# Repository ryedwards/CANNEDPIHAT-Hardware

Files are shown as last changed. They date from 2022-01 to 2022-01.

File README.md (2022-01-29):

# CANNEDPIHAT-Hardware
 
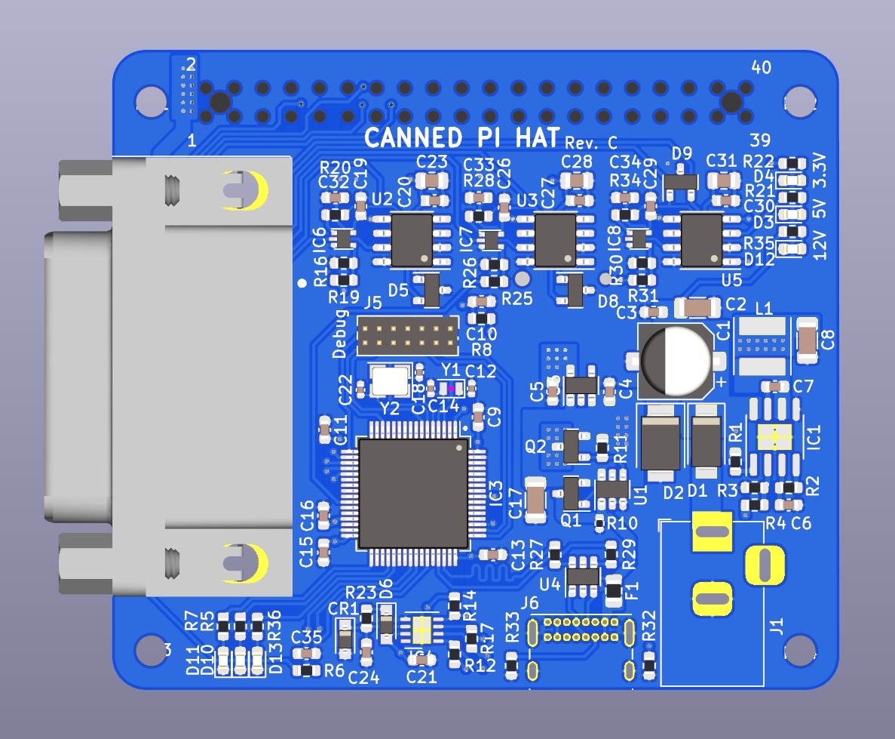
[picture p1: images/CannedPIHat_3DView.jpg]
CannedPiHat Front

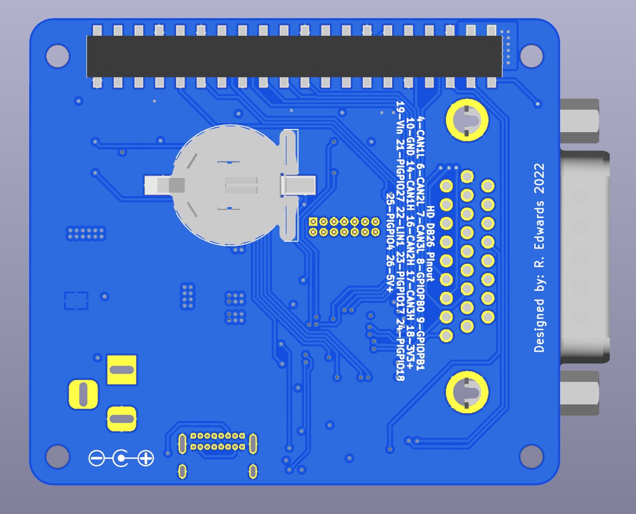
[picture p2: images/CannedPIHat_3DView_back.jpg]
CannedPiHat Front


## The CannedPi Hardware
Meet the CannedPi hardware!  This simple (and not prefectly designed) Raspberry PI Hat contains an STM32G4 microcontroller which can interface with the USB port of your Pi.

Why would I create such a Rube Goldberg design??
- I wanted a HAT that would provide provide solid 5V power from a ~12V power input.  This board has a 4A SMPS that provides more than enough juice for even a power hungry Pi4.
- I wanted the option of running both scripts on the Pi (Python-CAN, C applications, etc) while also having the ability to run real-time CAN on the embedded chip as needed.
- Wanted an "all-in-one" form factor for mounting on LCD displays and other small cases
- For LIN you really need the real time microcontroller
- I wanted to prove I could do it.  Now that I feel I've achived my goal I decided to share it wth everyone

## Features
- The 26-pin header provides access to all 3 CAN channels, the LIN channel, 12V, 5V, 3.3V and a few GPIO from both the PI and the SMT32G4.  Why a 26-pin?  Other CAN tools I'm using also utilize this header and I didn't feel like making new harnesses.  Besides, it's a nice form factor for getting a lot of I/O and there are cables available on Amazon.

## Notes
This design is provided in KiCad 6.0

## Disclaimers
It has not been EMI or EMC tested.  I am not a hardware engineer so I can't ensure that there aren't some design flaws.  I've sanity tested the prototypes and they seem to be stable and perform as expected.

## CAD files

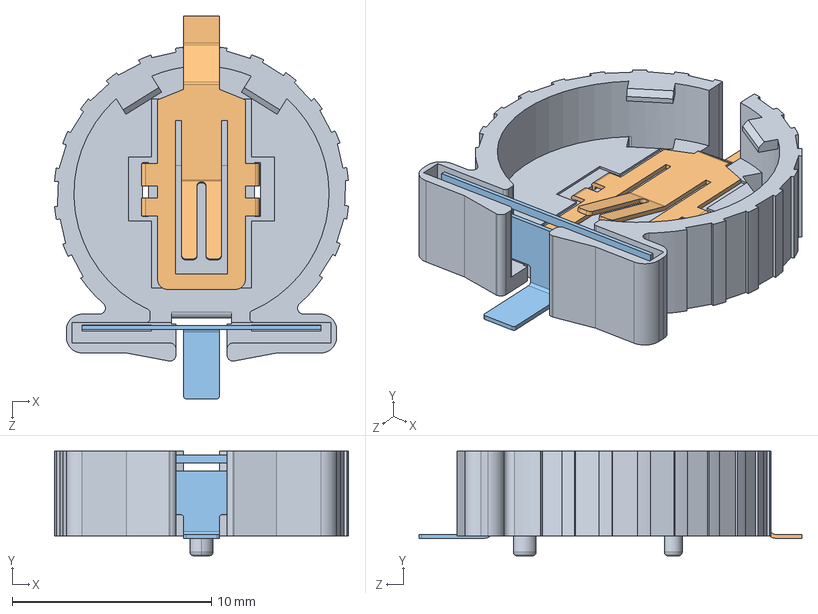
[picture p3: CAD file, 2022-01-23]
Custom_Parts/S8411-45R/3D/S8411-45R.stp
14.7 x 5.25 x 19.2 mm
Holder
Lower Contact
Rear Contact

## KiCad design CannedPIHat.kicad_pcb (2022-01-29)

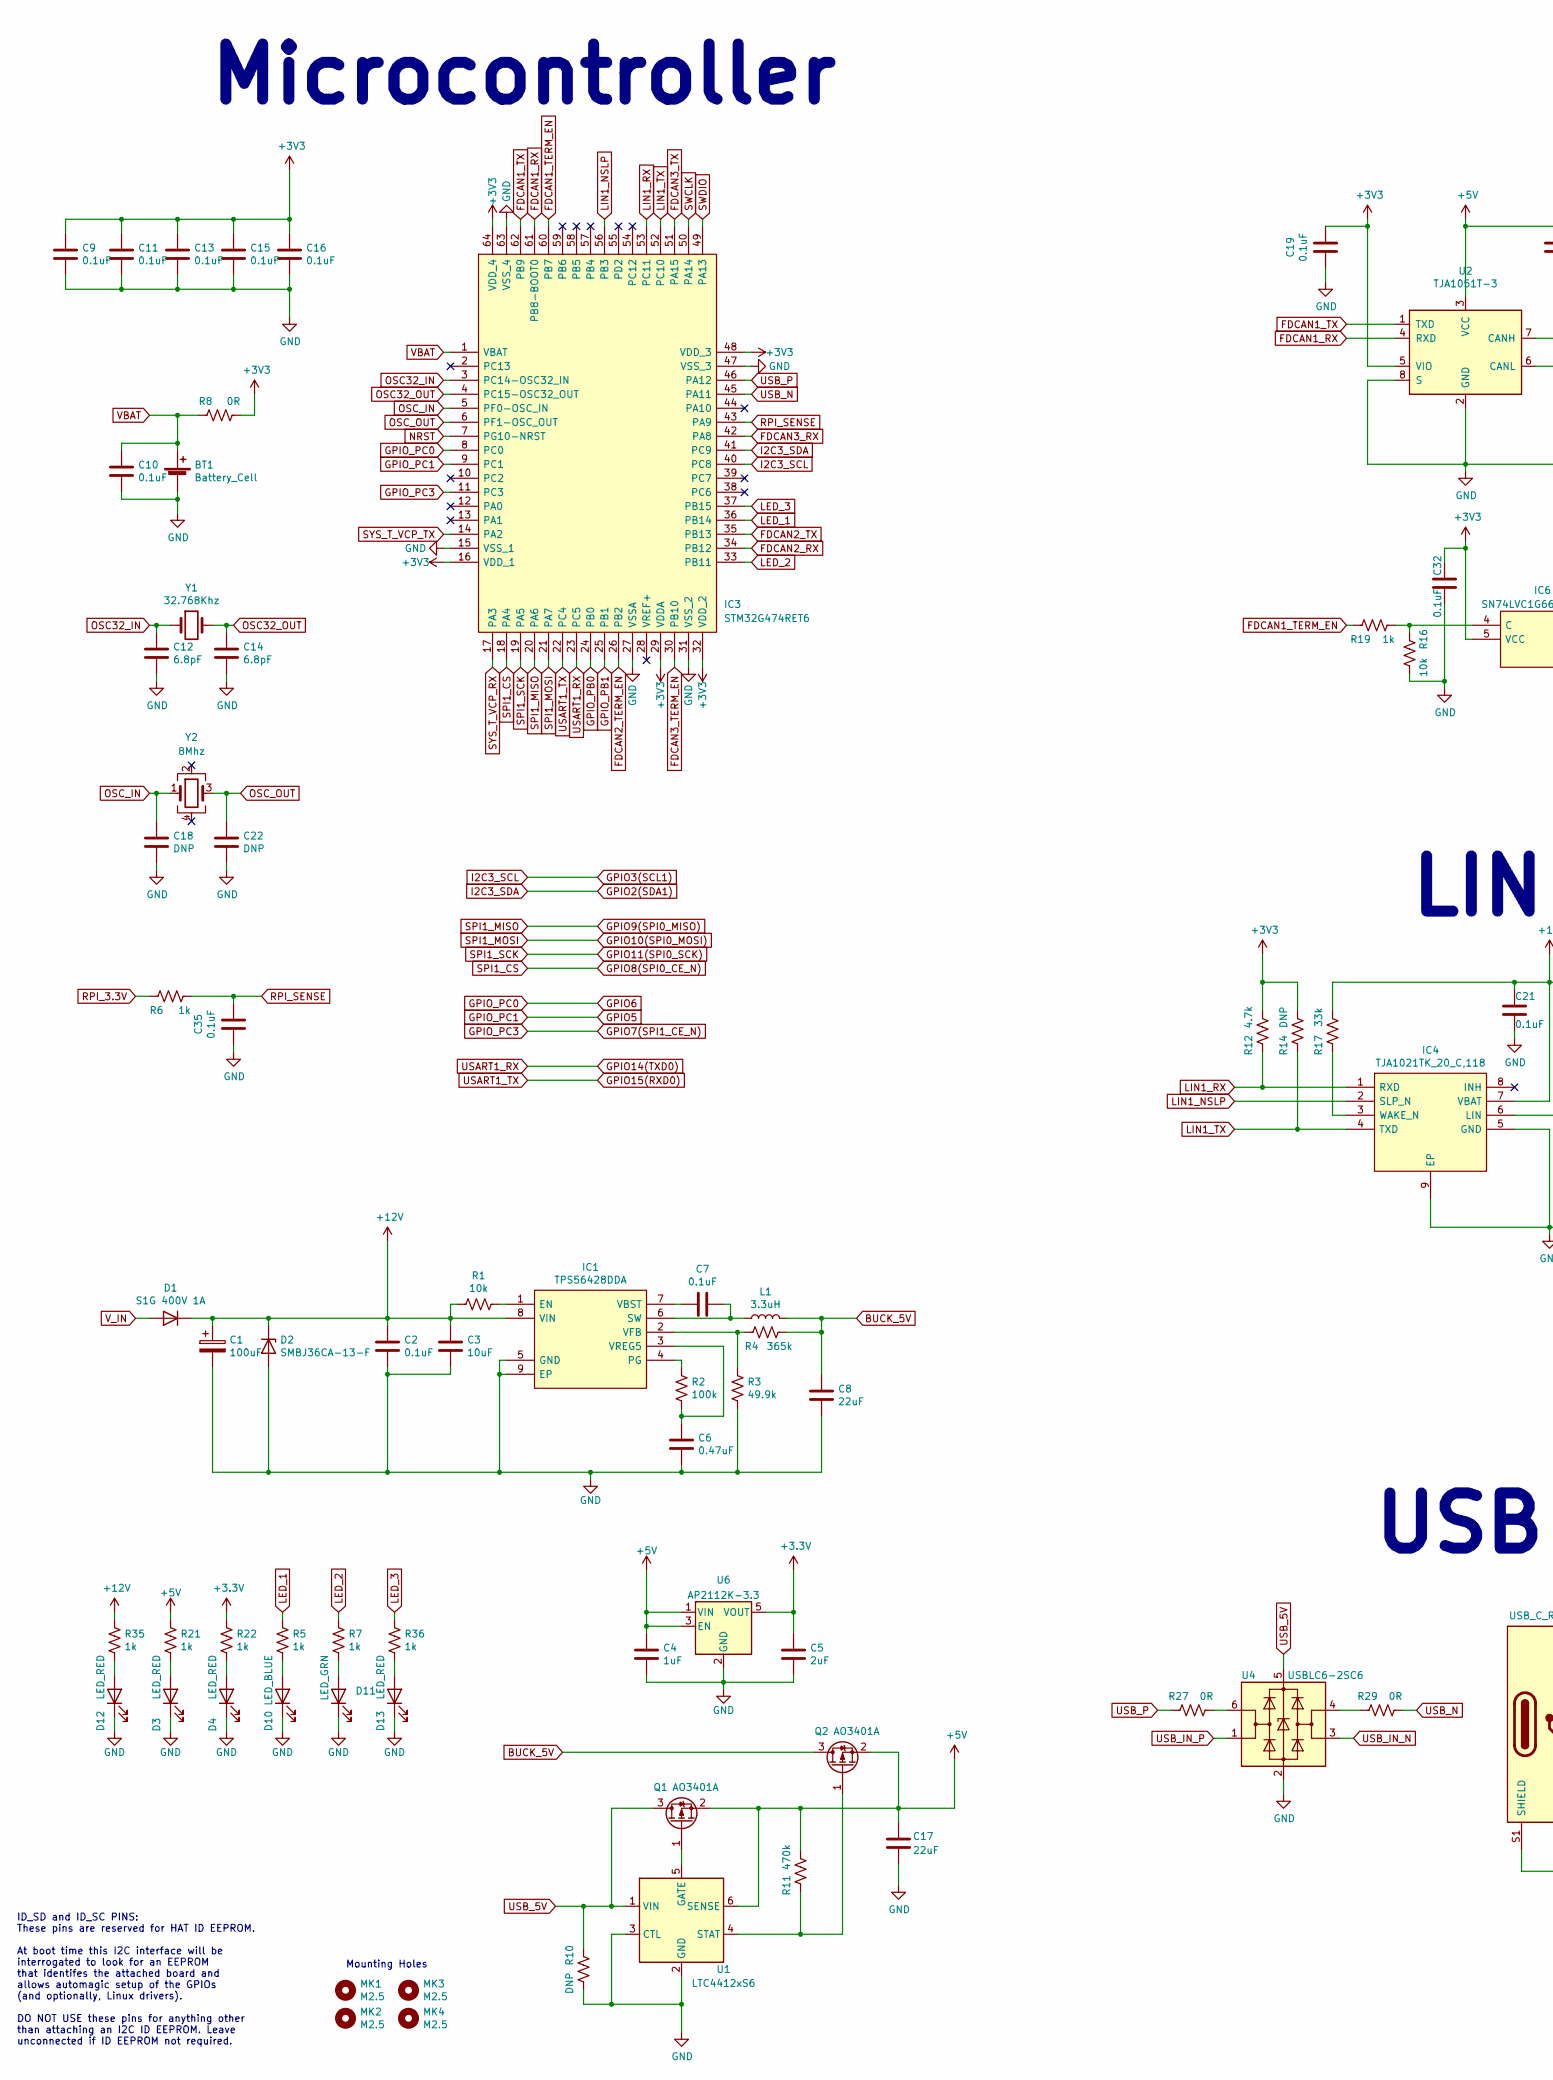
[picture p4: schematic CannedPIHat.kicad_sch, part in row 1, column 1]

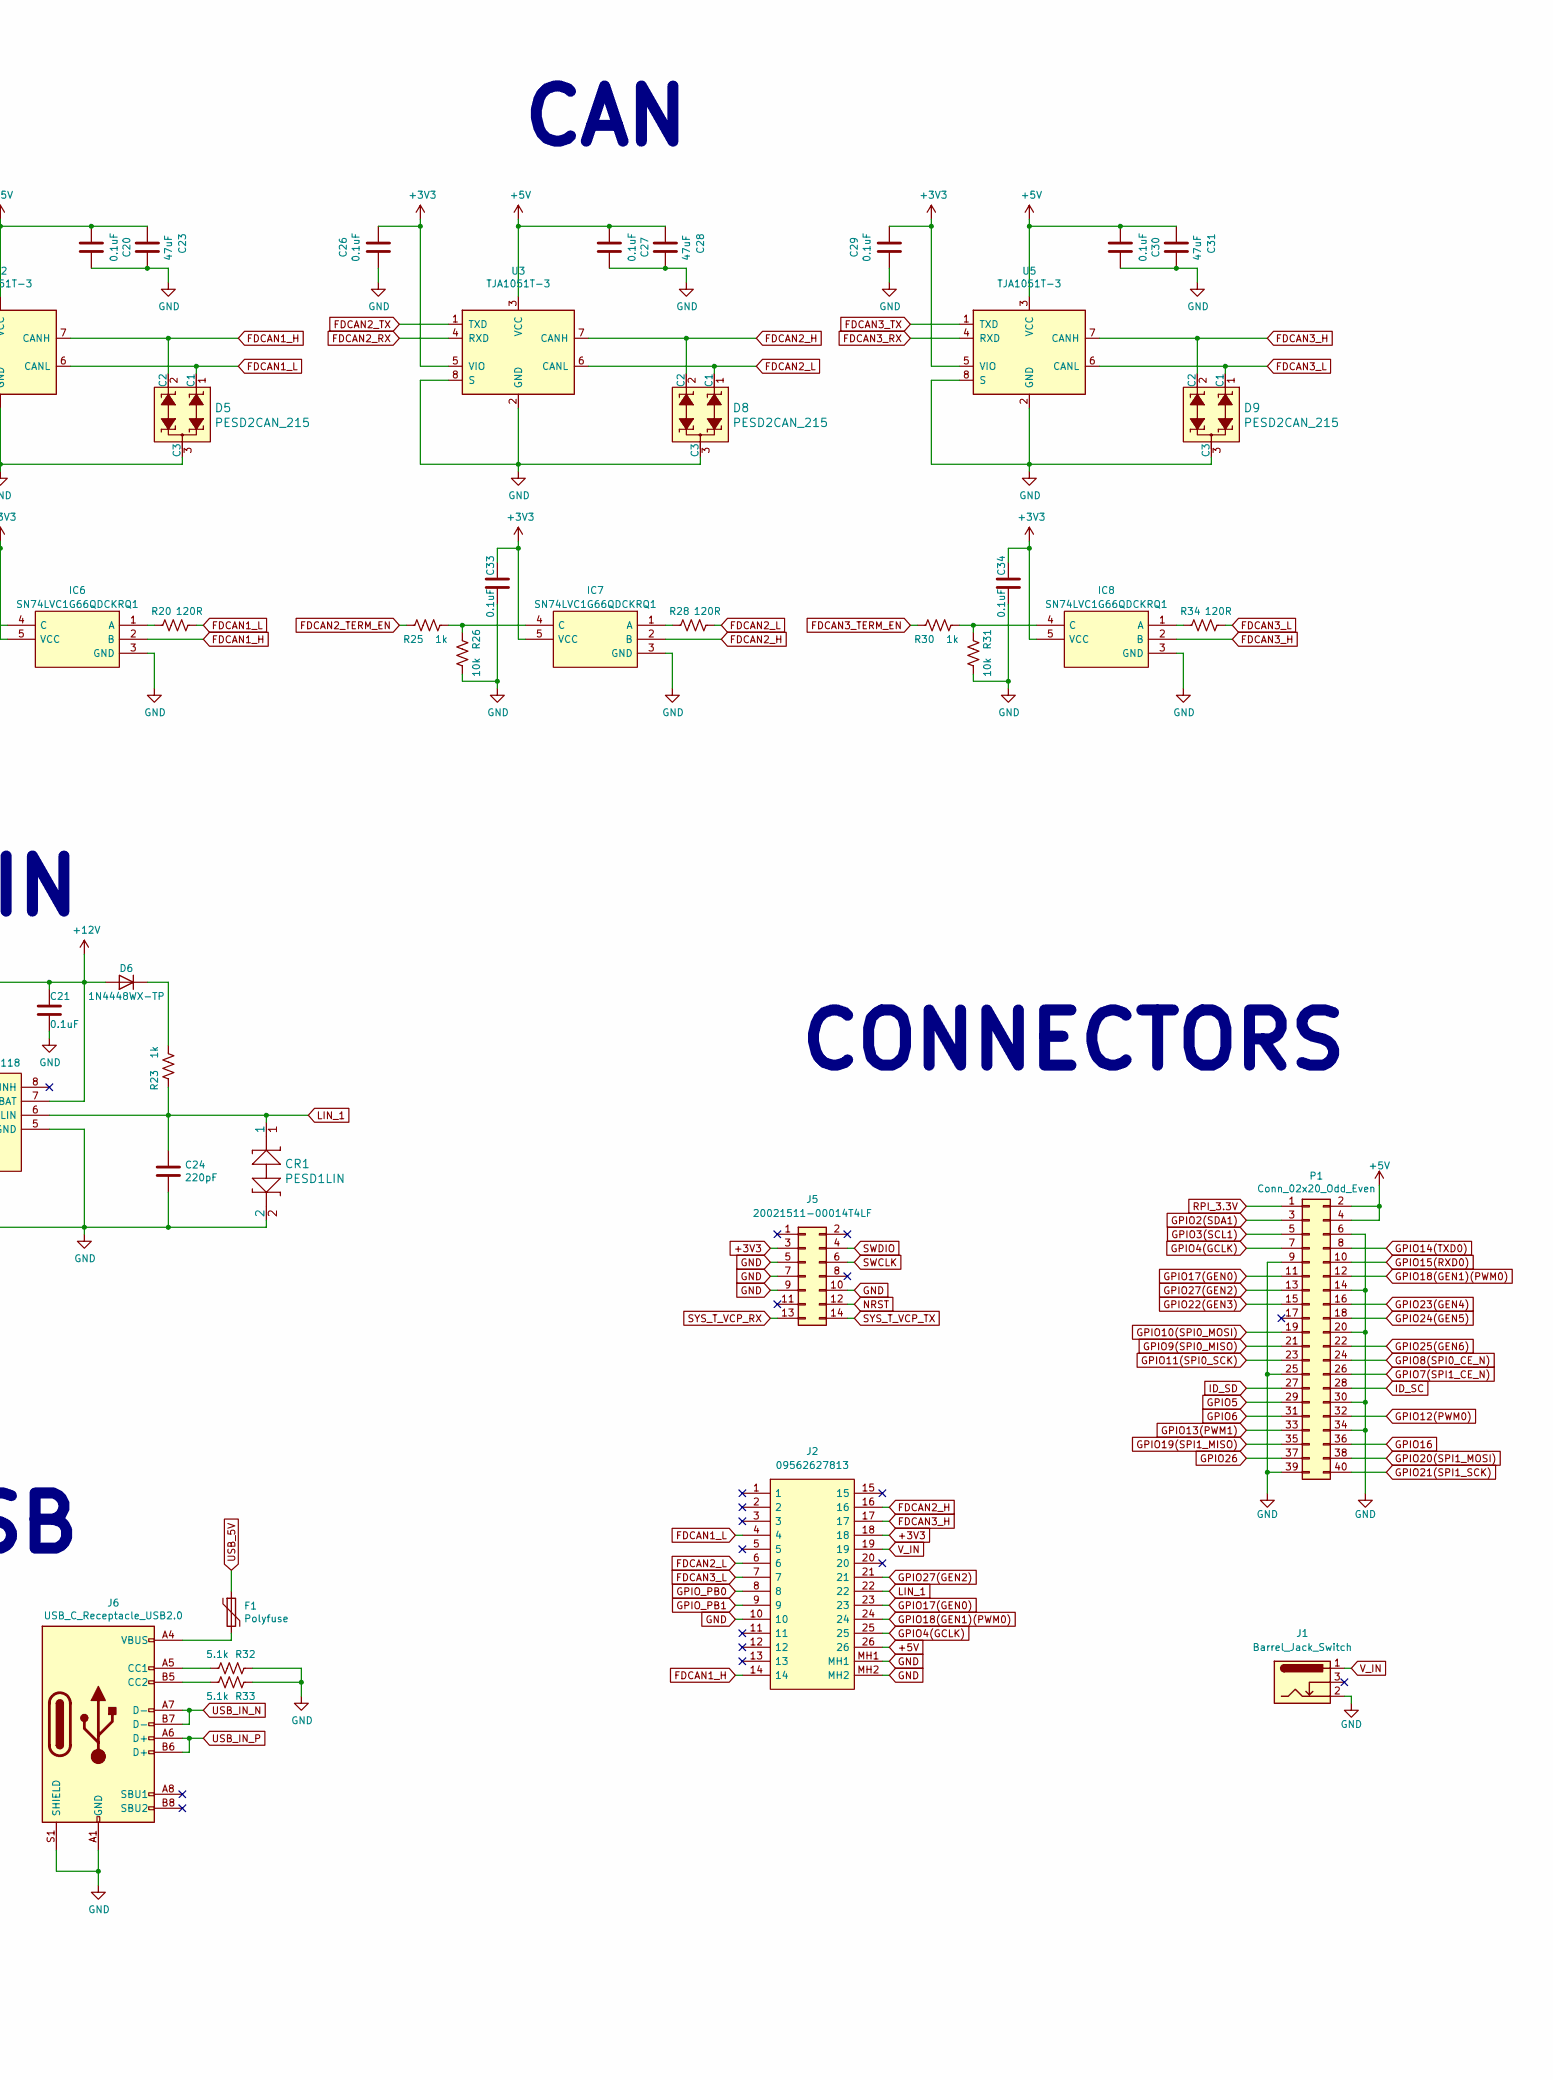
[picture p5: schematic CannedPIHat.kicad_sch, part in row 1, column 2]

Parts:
BT1: Battery_Cell; S8411-45R_1; Manufacturer_Part_Number S8411-45R; Digi-Key_PN 952-1745-1-ND
C1: 100uF; CP_Elec_6.3x7.7; Manufacturer_Part_Number EMZA250ADA101MF80G; LCSC Part # C127971
C2, C7, C9, C10, C11, C13, C15, C16, C19, C20, C21, C26, C27, C29, C30, C32, C33, C34, C35: 0.1uF; C_0603_1608Metric; Manufacturer_Part_Number CC0603KRX7R8BB104; LCSC Part # C14663
C3: 10uF; C_1206_3216Metric; Manufacturer_Part_Number CL31B106KQHNFNE; LCSC Part # C13585
C4: 1uF; C_0603_1608Metric; Manufacturer_Part_Number CC0603KRX7R8BB104; LCSC Part # C14663
C5: 2uF; C_0603_1608Metric; Manufacturer_Part_Number CC0603KRX7R8BB104; LCSC Part # C14663
C6: 0.47uF; C_0603_1608Metric; Manufacturer_Part_Number CGA3E2X7R2A472K080AA; LCSC Part # C2167812
C8, C17: 22uF; C_1206_3216Metric; Manufacturer_Part_Number EMK316ABJ226ML-T; LCSC Part # C12891
C12, C14: 6.8pF; C_0402_1005Metric; Manufacturer_Part_Number GRM1555C1H6R8CA01D; LCSC Part # C1576
C18, C22: DNP; C_0402_1005Metric; LCSC Part # C1576
C23, C28, C31: 47uF; C_0805_2012Metric; Manufacturer_Part_Number JMK212BBJ476MG-T; LCSC Part # C16780
C24: 220pF; C_0603_1608Metric; Manufacturer_Part_Number CC0603JRNPO9BN221; LCSC Part # C1603
CR1: PESD1LIN; D_SOD-323_HandSoldering; Manufacturer_Part_Number PESD1LIN,135; LCSC Part # C2831530
D1: S1G 400V 1A; D_SMA; Manufacturer_Part_Number S1G; LCSC Part # C412437
D2: SMBJ36CA-13-F; D_SMB; Manufacturer_Part_Number SMBJ36CA-13-F; LCSC Part # C78421
D3, D4, D12, D13: LED_RED; LED_0603_1608Metric; Manufacturer_Part_Number LS Q976-NR-1; LCSC Part # C2286
D5, D8, D9: PESD2CAN_215; SOT-23; MPN PESD2CAN,215; Digi-Key_PN 1727-3891-1-ND
D6: ‎1N4448WX-TP‎; D_SOD-323_HandSoldering; Manufacturer_Part_Number ‎1N4448WX-TP‎; Digi-Key_PN 1N4448WXTPMSCT-ND
D10: LED_BLUE; LED_0603_1608Metric; Manufacturer_Part_Number LB Q39E-N1OO-35-1; LCSC Part # C72041
D11: LED_GRN; LED_0603_1608Metric; Manufacturer_Part_Number LG Q396-PS-35; LCSC Part # C72043
F1: Polyfuse; Fuse_0805_2012Metric; Manufacturer_Part_Number 0ZCK0035FF2G; LCSC Part # C369150
IC1: TPS56428DDA; SOIC-8-1EP_3.9x4.9mm_P1.27mm_EP2.29x3mm_ThermalVias; Mouser Part Number 595-TPS56428DDA
IC3: STM32G474RET6; LQFP-64_10x10mm_P0.5mm; Mouser Part Number 511-STM32G474RET6
IC4: TJA1021TK_20_C,118; HVSON-8-1EP_3x3mm_P0.65mm_EP1.6x2.4mm; Mouser Part Number 771-TJA1021TK20C1
IC6, IC7, IC8: SN74LVC1G66QDCKRQ1; SOT-665; Mouser Part Number 595-LVC1G66QDCKRQ1
J1: Barrel_Jack_Switch; BarrelJack_Horizontal
J2: 09562627813; Manufacturer_Part_Number 09562627813; Mouser Part Number 617-09-56-262-7813
J5: 20021511-00014T4LF; PinHeader_2x07_P1.27mm_Vertical; Mouser Part Number 200-FTSH10701LDK
J6: USB_C_Receptacle_USB2.0; USB_C_Receptacle_GCT_USB4085; Manufacturer_Part_Number USB4085-GF-A; Digi-Key_PN 2073-USB4085-GF-ACT-ND
L1: 3.3uH; L_Taiyo-Yuden_NR-50xx; LCSC Part # C167908
MK1, MK2, MK3, MK4: M2.5; MountingHole_2.7mm_M2.5
P1: Conn_02x20_Odd_Even; M207812045_MIRROR; Manufacturer_Part_Number M20-7812045R; Digi-Key_PN 952-3230-2-ND
Q1, Q2: AO3401A; SOT-23; LCSC Part # C15127
R1, R16, R26, R31: 10k; R_0603_1608Metric; Manufacturer_Part_Number RC0603FR-0710KL; LCSC Part # C25804
R2: 100k; R_0603_1608Metric; Manufacturer_Part_Number RC0603FR-07100KL; LCSC Part # C25803
R3: 49.9k; R_0603_1608Metric; Manufacturer_Part_Number AF0603FR-0749K9L; LCSC Part # C23184
R4: 365k; R_0603_1608Metric; Manufacturer_Part_Number 13-AC0603FR-07365KLCT-ND; LCSC Part # C23031
R5, R6, R7, R19, R21, R22, R23, R25, R30, R35, R36: 1k; R_0603_1608Metric; Manufacturer_Part_Number RC0603FR-071KL; LCSC Part # C21190
R8, R27, R29: 0R; R_0603_1608Metric; Manufacturer_Part_Number RC0603JR-070RL; LCSC Part # C21189
R10: DNP; R_0402_1005Metric
R11: 470k; R_0603_1608Metric; LCSC Part # C23178
R12: 4.7k; R_0603_1608Metric; Manufacturer_Part_Number RC0603JR-074K7L; LCSC Part # C23162
R14: DNP; R_0603_1608Metric
R17: 33k; R_0603_1608Metric; Manufacturer_Part_Number RC0603FR-0733K2L; LCSC Part # C4216
R20, R28, R34: 120R; R_0603_1608Metric; Manufacturer_Part_Number RC0603FR-07120RL; LCSC Part # C22787
R32, R33: 5.1k; R_0603_1608Metric; Manufacturer_Part_Number RC0603JR-075K1L; LCSC Part # C23186
U1: LTC4412xS6; TSOT-23-6; LCSC Part # C514442
U2, U3, U5: TJA1051T-3; SOIC-8_3.9x4.9mm_P1.27mm; LCSC Part # C38695
U4: USBLC6-2SC6; SOT-23-6; Manufacturer_Part_Number USBLC6-2SC6; LCSC Part # C2687116
U6: AP2112K-3.3; SOT-23-5
Y1: 32.768Khz; Crystal_SMD_2012-2Pin_2.0x1.2mm; Manufacturer_Part_Number ECS-.327-6-12-C-TR; LCSC Part # C276423
Y2: 8Mhz; Crystal_SMD_3225-4Pin_3.2x2.5mm

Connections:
+5V: C4.1, C17.1, C20.2, C23.1, C27.2, C28.1, C30.2, C31.1, J2.26, P1.2, P1.4, Q1.2 (S), Q2.2 (S), R11.2, R21.2, U1.6 (SENSE), U2.3 (VCC), U3.3 (VCC), U5.3 (VCC), U6.1 (VIN), U6.3 (EN)
+12V: C1.1, C2.1, C3.1, C21.1, D1.1 (K), D2.1 (K), D6.2 (A), IC1.8 (VIN), IC4.7 (VBAT), R1.2, R17.2, R35.2
BUCK_5V: C8.1, L1.2, Q2.3 (D), R4.1
FDCAN1_H: D5.2 (C2), IC6.2 (B), J2.14, U2.7 (CANH)
FDCAN1_L: D5.1 (C1), J2.4, R20.2, U2.6 (CANL)
FDCAN1_RX: IC3.61 (PB8-BOOT0), U2.4 (RXD)
FDCAN1_TERM_EN: IC3.60 (PB7), R19.1
FDCAN1_TX: IC3.62 (PB9), U2.1 (TXD)
FDCAN2_H: D8.2 (C2), IC7.2 (B), J2.16, U3.7 (CANH)
FDCAN2_L: D8.1 (C1), J2.6, R28.2, U3.6 (CANL)
FDCAN2_RX: IC3.34 (PB12), U3.4 (RXD)
FDCAN2_TERM_EN: IC3.26 (PB2), R25.1
FDCAN2_TX: IC3.35 (PB13), U3.1 (TXD)
FDCAN3_H: D9.2 (C2), IC8.2 (B), J2.17, U5.7 (CANH)
FDCAN3_L: D9.1 (C1), J2.7, R34.2, U5.6 (CANL)
FDCAN3_RX: IC3.42 (PA8), U5.4 (RXD)
FDCAN3_TERM_EN: IC3.30 (PB10), R30.1
FDCAN3_TX: IC3.51 (PA15), U5.1 (TXD)
GND: BT1.2 (-), C1.2, C2.2, C3.2, C4.2, C5.2, C6.2, C8.2, C9.2, C10.2, C11.2, C12.2, C13.2, C14.2, C15.2, C16.2, C17.2, C18.2, C19.2, C20.1, C21.2, C22.2, C23.2, C24.2, C26.2, C27.1, C28.2, C29.2, C30.1, C31.2, C32.2, C33.2, C34.2, C35.2, CR1.2, D2.2 (A), D3.1 (K), D4.1 (K), D5.3 (C3), D8.3 (C3), D9.3 (C3), D10.1 (K), D11.1 (K), D12.1 (K), D13.1 (K), IC1.5 (GND), IC1.9 (EP), IC3.15 (VSS_1), IC3.27 (VSSA), IC3.31 (VSS_2), IC3.47 (VSS_3), IC3.63 (VSS_4), IC4.5 (GND), IC4.9 (EP), IC6.3 (GND), IC7.3 (GND), IC8.3 (GND), J1.2, J2.10, J2.MH1, J2.MH2, J5.5, J5.7, J5.9, J5.10, J6.A1 (GND), J6.A12 (GND), J6.B1 (GND), J6.B12 (GND), J6.S1 (SHIELD), P1.6, P1.9, P1.14, P1.20, P1.25, P1.30, P1.34, P1.39, R3.2, R10.2, R16.2, R26.2, R31.2, R32.1, R33.1, U1.2 (GND), U1.3 (CTL), U2.2 (GND), U2.8 (S), U3.2 (GND), U3.8 (S), U4.2 (GND), U5.2 (GND), U5.8 (S), U6.2 (GND)
GPIO2(SDA1): IC3.41 (PC9), P1.3
GPIO3(SCL1): IC3.40 (PC8), P1.5
GPIO4(GCLK): J2.25, P1.7
GPIO5: IC3.9 (PC1), P1.29
GPIO6: IC3.8 (PC0), P1.31
GPIO7(SPI1_CE_N): IC3.11 (PC3), P1.26
GPIO8(SPI0_CE_N): IC3.18 (PA4), P1.24
GPIO9(SPI0_MISO): IC3.20 (PA6), P1.21
GPIO10(SPI0_MOSI): IC3.21 (PA7), P1.19
GPIO11(SPI0_SCK): IC3.19 (PA5), P1.23
GPIO12(PWM0): P1.32
GPIO13(PWM1): P1.33
GPIO14(TXD0): IC3.23 (PC5), P1.8
GPIO15(RXD0): IC3.22 (PC4), P1.10
GPIO16: P1.36
GPIO17(GEN0): J2.23, P1.11
GPIO18(GEN1)(PWM0): J2.24, P1.12
GPIO19(SPI1_MISO): P1.35
GPIO20(SPI1_MOSI): P1.38
GPIO21(SPI1_SCK): P1.40
GPIO22(GEN3): P1.15
GPIO23(GEN4): P1.16
GPIO24(GEN5): P1.18
GPIO25(GEN6): P1.22
GPIO26: P1.37
GPIO27(GEN2): J2.21, P1.13
GPIO_PB0: IC3.24 (PB0), J2.8
GPIO_PB1: IC3.25 (PB1), J2.9
ID_SC: P1.28
ID_SD: P1.27
LED_1: IC3.36 (PB14), R5.2
LED_2: IC3.33 (PB11), R7.2
LED_3: IC3.37 (PB15), R36.2
LIN1_NSLP: IC3.56 (PB3), IC4.2 (SLP_N)
LIN1_RX: IC3.53 (PC11), IC4.1 (RXD), R12.1
LIN1_TX: IC3.52 (PC10), IC4.4 (TXD), R14.1
LIN_1: C24.1, CR1.1, IC4.6 (LIN), J2.22, R23.1
NRST: IC3.7 (PG10-NRST), J5.12
unnamed: C6.1, IC1.3 (VREG5), R2.2
unnamed: C7.1, IC1.6 (SW), L1.1
unnamed: C7.2, IC1.7 (VBST)
unnamed: D3.2 (A), R21.1
unnamed: D4.2 (A), R22.1
unnamed: D6.1 (K), R23.2
unnamed: D10.2 (A), R5.1
unnamed: D11.2 (A), R7.1
unnamed: D12.2 (A), R35.1
unnamed: D13.2 (A), R36.1
unnamed: F1.2, J6.A4 (VBUS), J6.A9 (VBUS), J6.B4 (VBUS), J6.B9 (VBUS)
unnamed: IC1.1 (EN), R1.1
unnamed: IC1.2 (VFB), R3.1, R4.2
unnamed: IC1.4 (PG), R2.1
unnamed: IC4.3 (WAKE_N), R17.1
unnamed: IC6.1 (A), R20.1
unnamed: IC6.4 (C), R16.1, R19.2
unnamed: IC7.1 (A), R28.1
unnamed: IC7.4 (C), R25.2, R26.1
unnamed: IC8.1 (A), R34.1
unnamed: IC8.4 (C), R30.2, R31.1
unnamed: J6.A5 (CC1), R32.2
unnamed: J6.B5 (CC2), R33.2
unnamed: Q1.1 (G), U1.5 (GATE)
unnamed: Q2.1 (G), R11.1, U1.4 (STAT)
unnamed: R27.2, U4.6 (I/O1)
unnamed: R29.1, U4.4 (I/O2)
OSC32_IN: C12.1, IC3.3 (PC14-OSC32_IN), Y1.1
OSC32_OUT: C14.1, IC3.4 (PC15-OSC32_OUT), Y1.2
OSC_IN: C18.1, IC3.5 (PF0-OSC_IN), Y2.1
OSC_OUT: C22.1, IC3.6 (PF1-OSC_OUT), Y2.3
RPI_3.3V: P1.1, R6.1
RPI_SENSE: C35.1, IC3.43 (PA9), R6.2
SWCLK: IC3.50 (PA14), J5.6
SWDIO: IC3.49 (PA13), J5.4
SYS_T_VCP_RX: IC3.17 (PA3), J5.13
SYS_T_VCP_TX: IC3.14 (PA2), J5.14
USB_5V: F1.1, Q1.3 (D), R10.1, U1.1 (VIN), U4.5 (VBUS)
USB_IN_N: J6.A7 (D-), J6.B7 (D-), U4.3 (I/O2)
USB_IN_P: J6.A6 (D+), J6.B6 (D+), U4.1 (I/O1)
USB_N: IC3.45 (PA11), R29.2
USB_P: IC3.46 (PA12), R27.1
VBAT: BT1.1 (+), C10.1, IC3.1 (VBAT), R8.1
V_IN: D1.2 (A), J1.1, J2.19

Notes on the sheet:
Mounting Holes
CAN
LIN
Microcontroller
USB
CONNECTORS
ID_SD and ID_SC PINS: These pins are reserved for HAT ID EEPROM. At boot time this I2C interface will be interrogated to look for an EEPROM that identifes the attached board and allows automagic setup of the GPIOs (and optionally, Linux drivers). DO NOT USE these pins for anything other than attach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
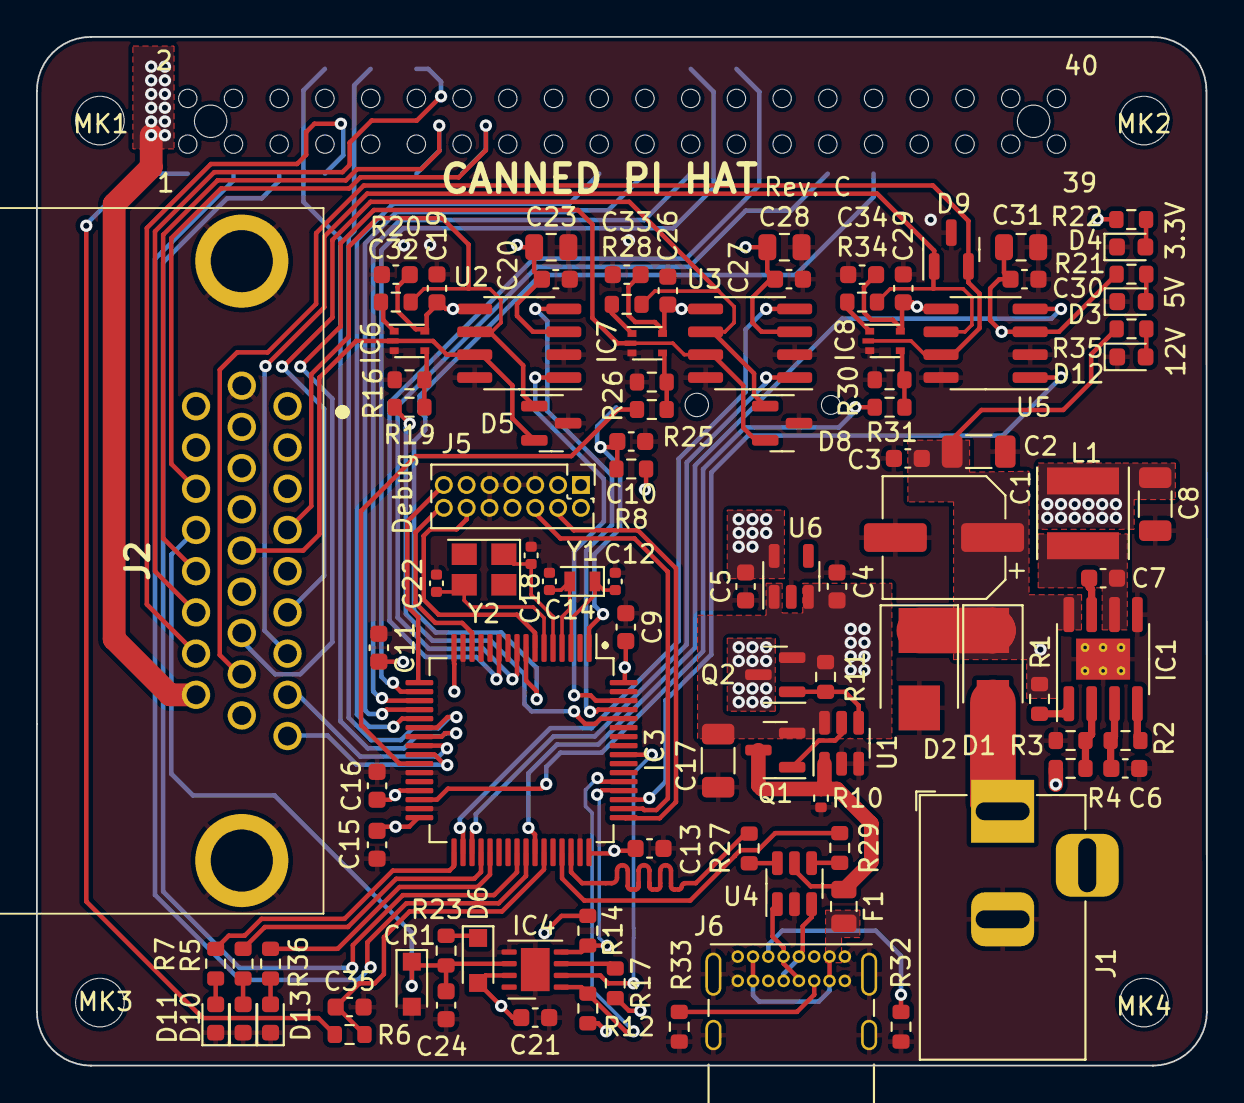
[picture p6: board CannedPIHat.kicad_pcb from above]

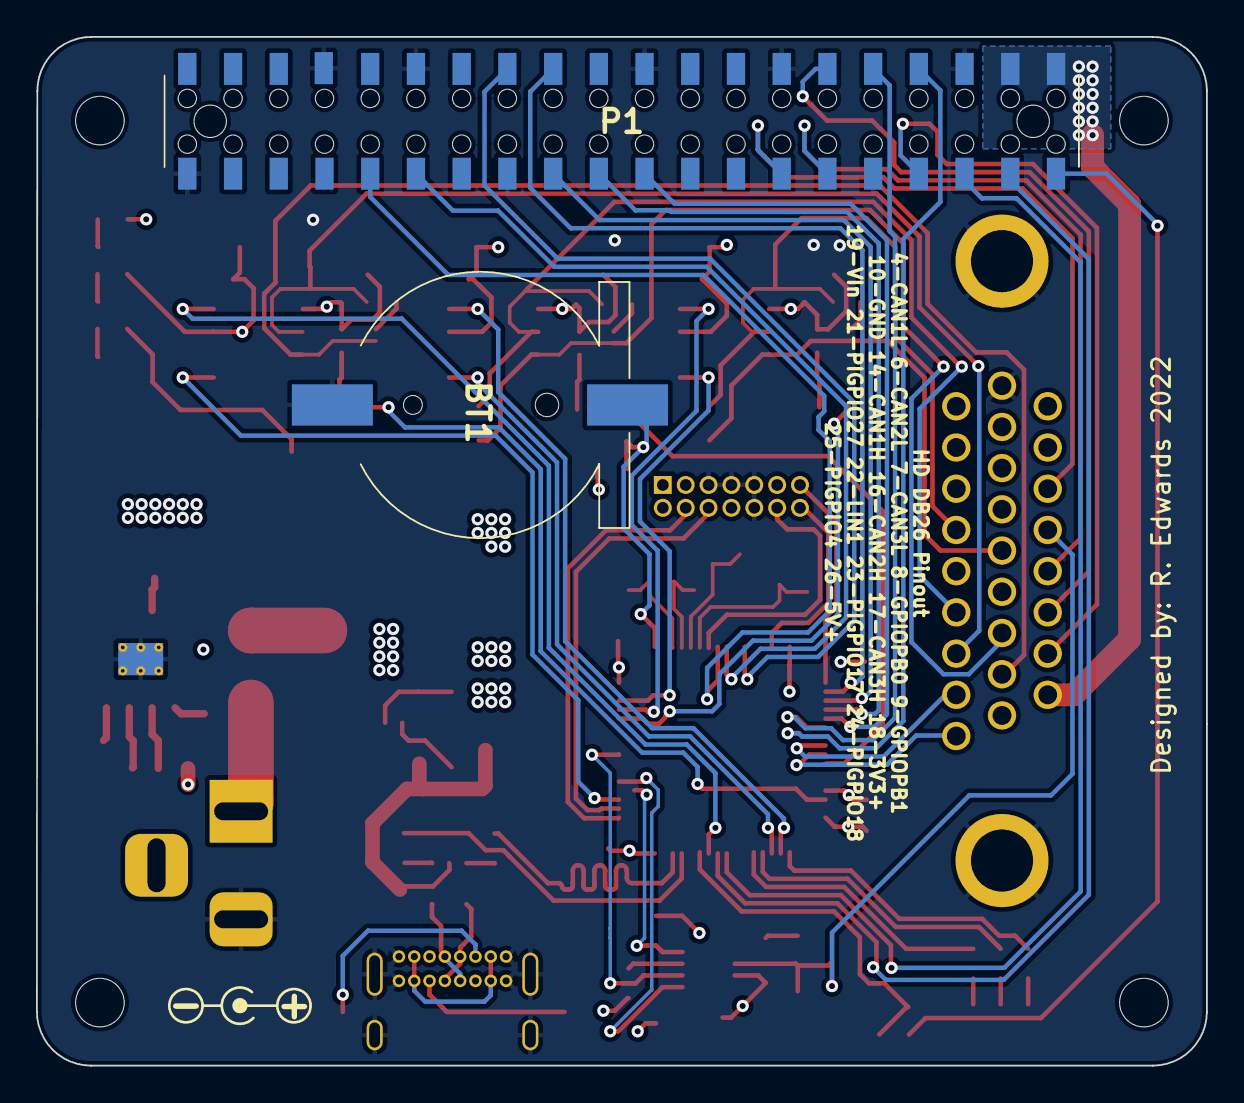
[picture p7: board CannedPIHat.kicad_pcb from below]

Board: 4 copper layers, 65.0 x 57.2 mm, 106 parts (2 on the bottom side), 89 nets.

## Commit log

2022-01-23 Add an image of the board
2022-01-29 Update to Rev C.
    [CannedPIHat.kicad_pcb, CannedPIHat.kicad_sch]
2022-01-29 Fix silkscreen
    [CannedPIHat.kicad_pcb]
